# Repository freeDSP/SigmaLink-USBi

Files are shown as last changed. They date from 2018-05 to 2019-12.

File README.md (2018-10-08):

# SigmaLink USBi

The SigmaLink USBi is an all-in-one real-time programming interface.

MAIN COORDINATOR: [Max Chan](https://github.com/xcvista)

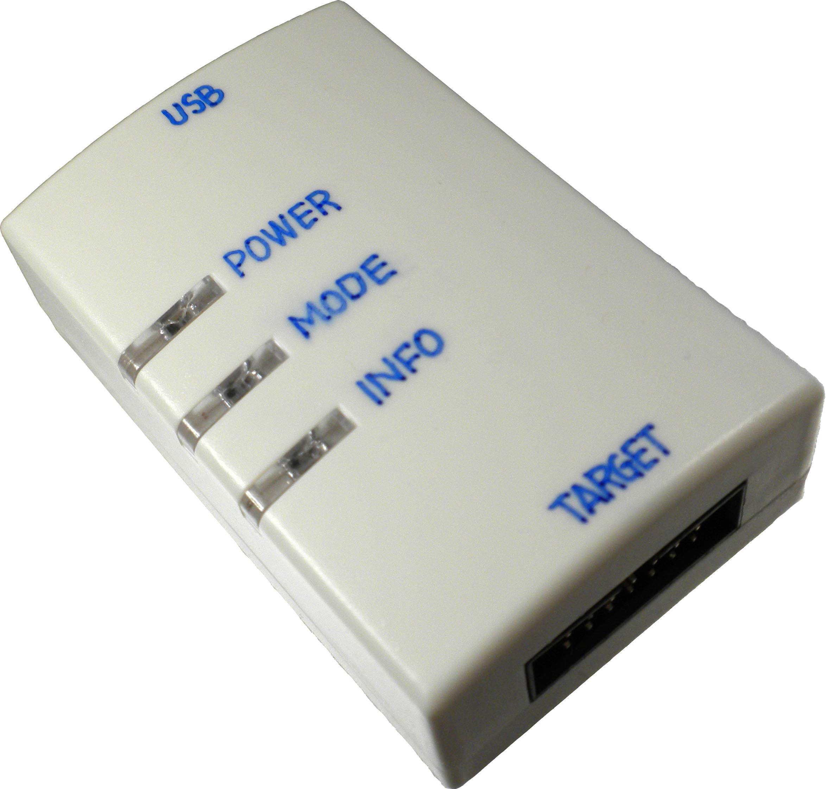
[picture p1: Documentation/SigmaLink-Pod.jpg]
SigmaLink USBi Pod Image


The SigmaLink USBi is a low-budget real-time programming device for the freeDSP and other DSP boards from Analog Devices. It is a new PCB design based on a CY7C68013 chip.

It has the same features as the Analog Devices USB interface (EVAL-ADUSB2EBZ), such as changing parameters while already using the freeDSP or easy changes of the schematic in SigmaStudio. You also can write your program to the EEPROM.

Please refer to the documentation for more information:

[Google Doc](https://docs.google.com/document/d/13BDac6Mss2I0CBOsSrk4YG-c8GQUpgU41vkwsMnYBss/edit?usp=sharing)

## License

This work and all other materials under https://github.com/freeDSP are licensed under a [Creative Commons Attribution Share-Alike 4.0 license](LICENSE.md). This allows for both personal and commercial derivative works, as long as they credit freeDSP and release their designs under the same license.

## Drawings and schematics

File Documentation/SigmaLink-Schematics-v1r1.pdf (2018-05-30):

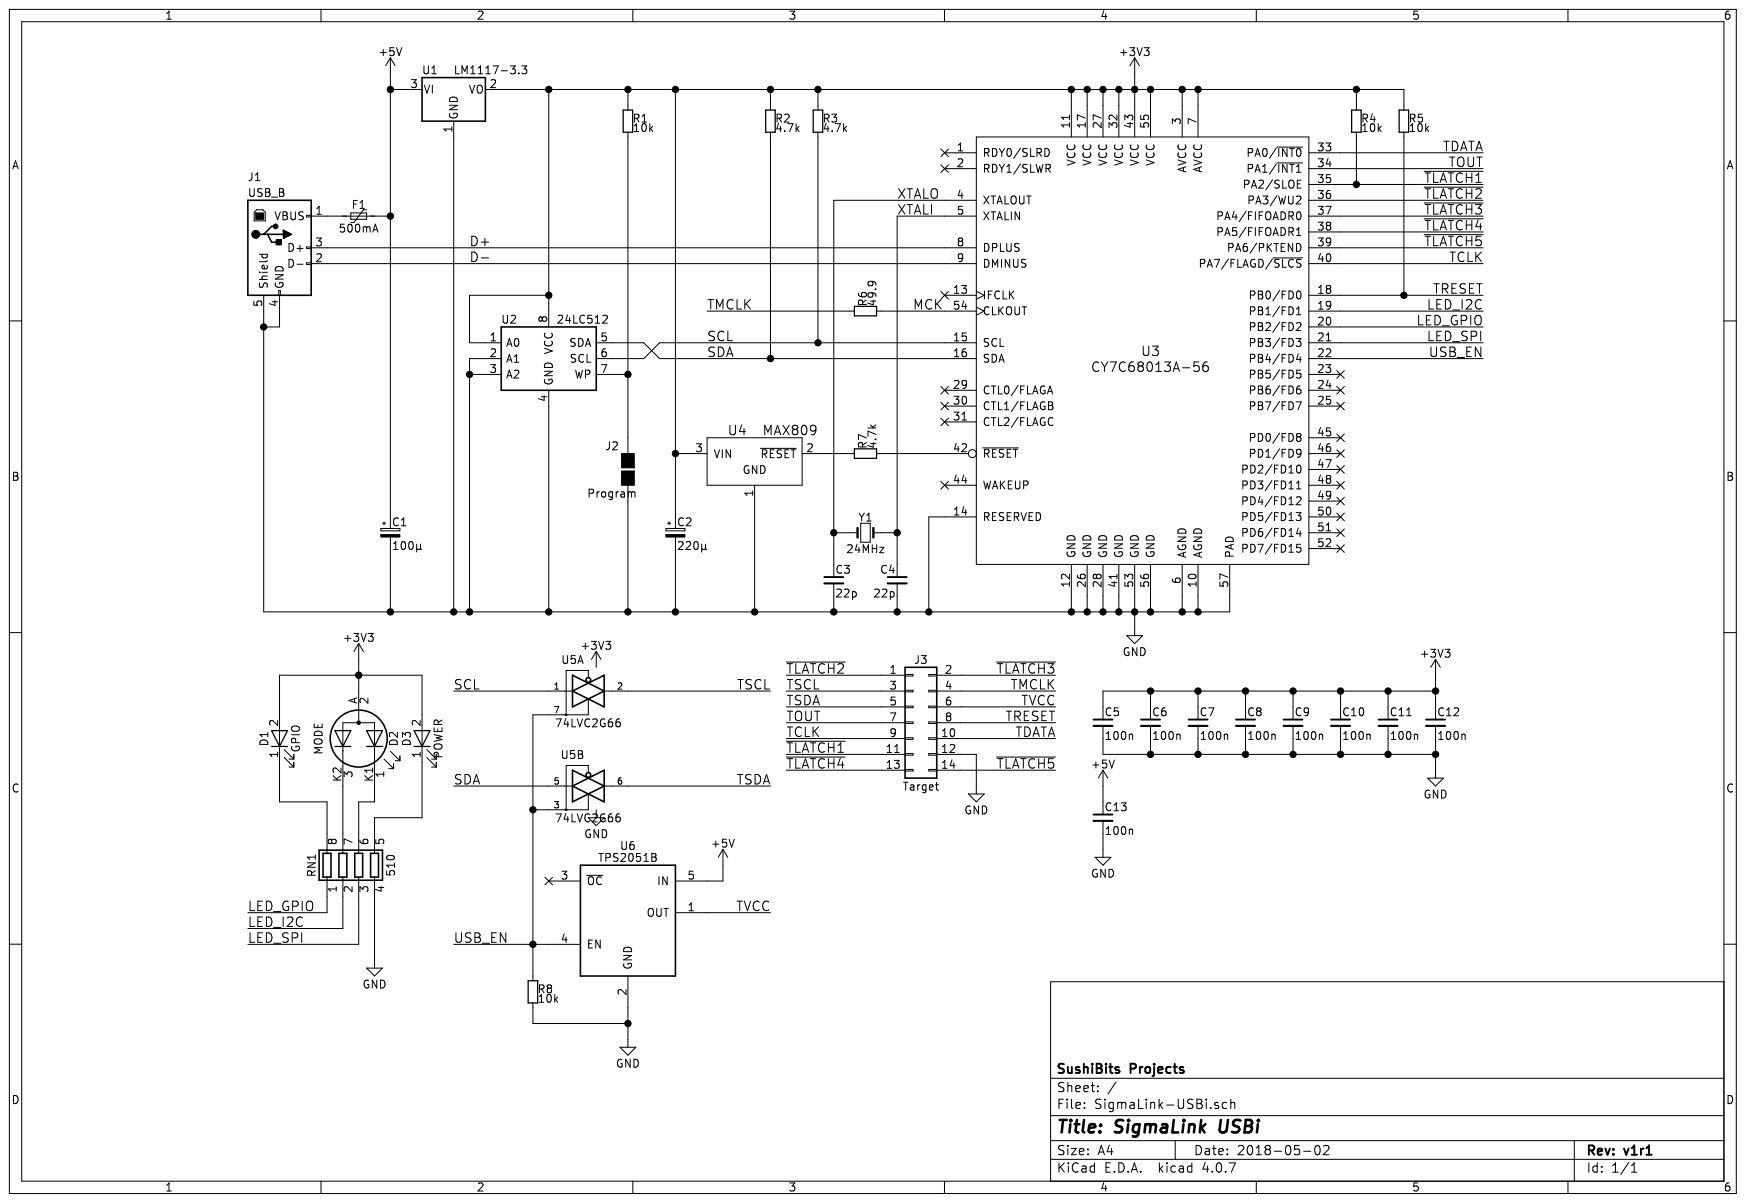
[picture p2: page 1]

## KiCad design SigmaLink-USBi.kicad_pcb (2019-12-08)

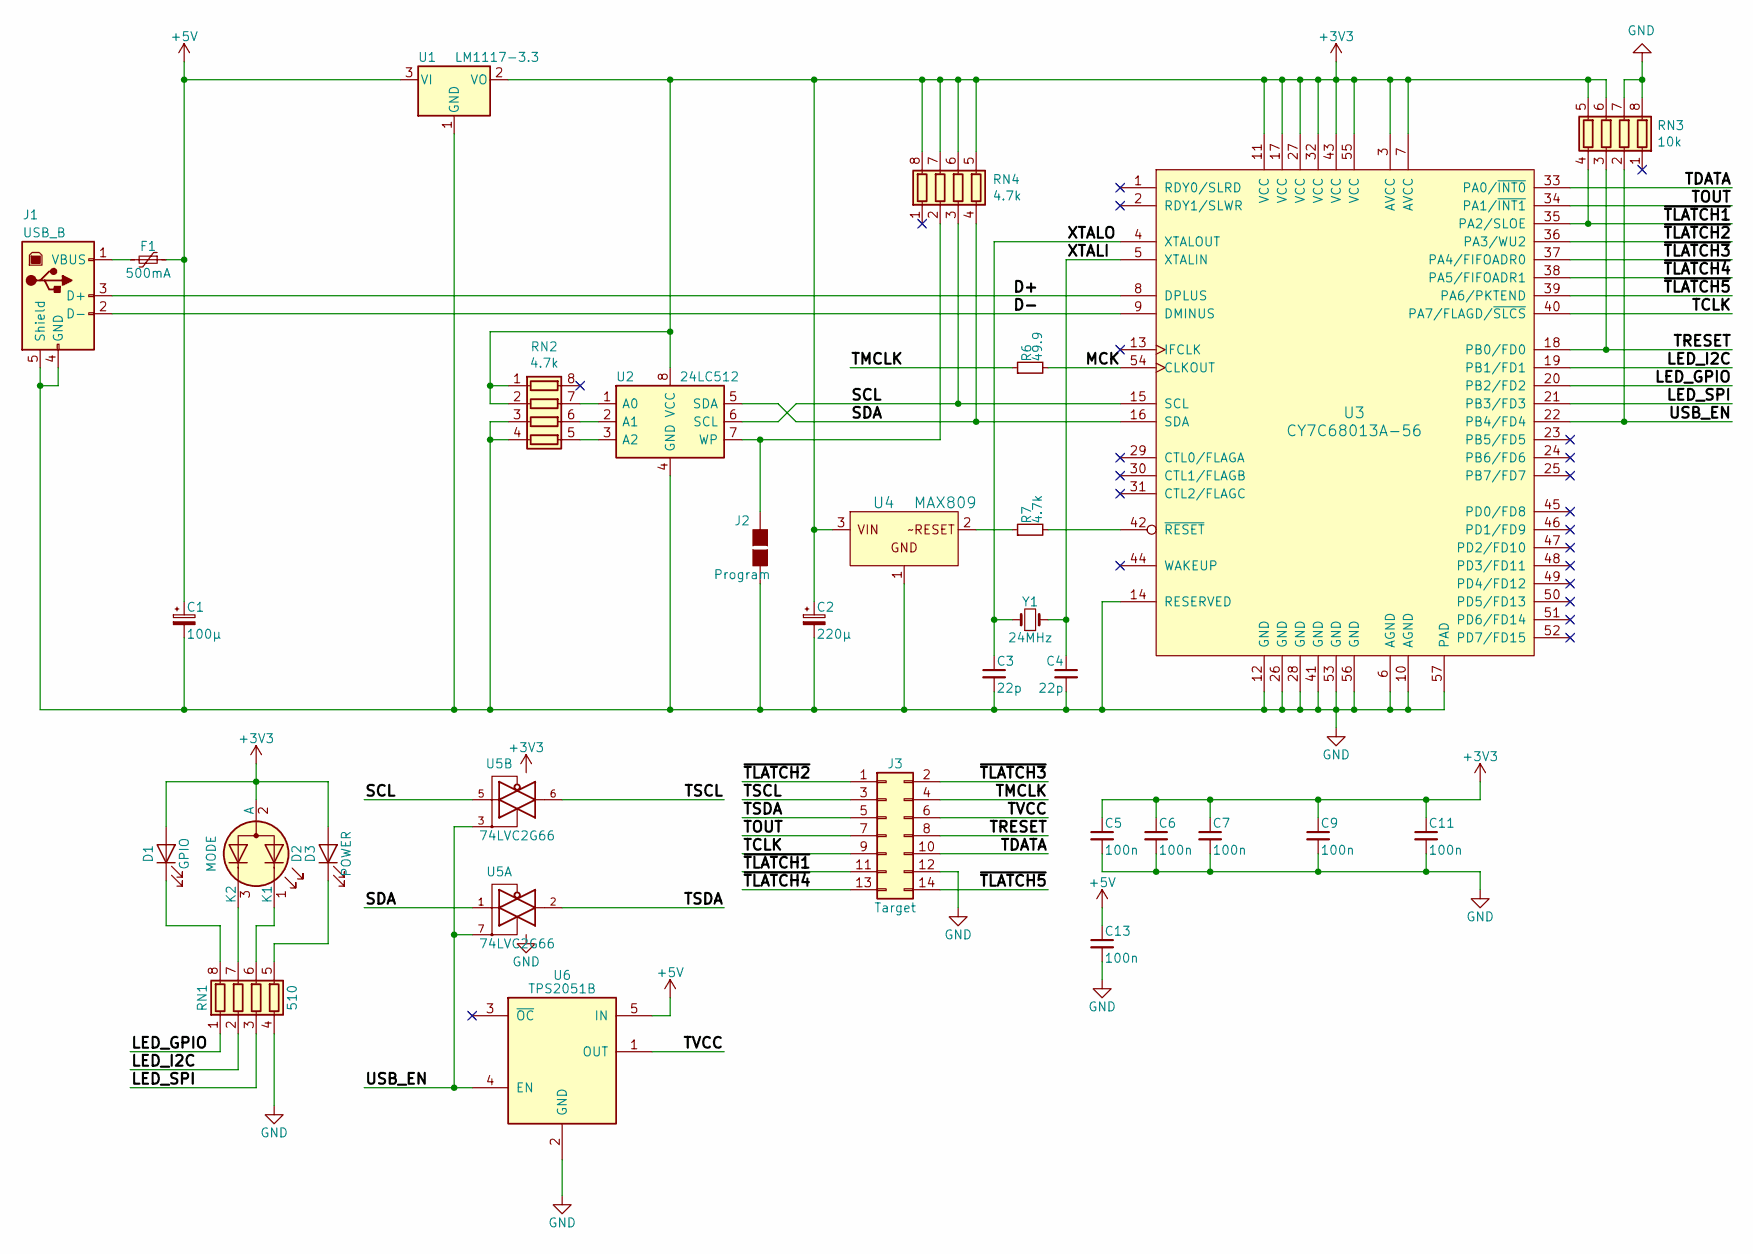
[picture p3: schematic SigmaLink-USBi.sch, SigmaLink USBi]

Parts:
C1: 100µ; CP_Elec_6.3x5.3
C2: 220µ; CP_Elec_6.3x5.3
C3, C4: 22p; C_0603_1608Metric_Pad1.05x0.95mm_HandSolder
C5, C6, C7, C9, C11, C13: 100n; C_0603_1608Metric_Pad1.05x0.95mm_HandSolder
D1: GPIO; LED_D3.0mm
D2: MODE; LED_D3.0mm-3
D3: POWER; LED_D3.0mm
F1: 500mA; Fuse_1812_4532Metric_Pad1.30x3.40mm_HandSolder
J1: USB_B; USB_B_OST_USB-B1HSxx_Horizontal
J2: Program; PinHeader_2x01_P1.27mm_Vertical
J3: Target; IDC-Header_2x07_P2.54mm_Horizontal
R6: 49.9; R_0603_1608Metric_Pad1.05x0.95mm_HandSolder
R7: 4.7k; R_0603_1608Metric_Pad1.05x0.95mm_HandSolder
RN1: 510; R_Array_Convex_4x0603
RN2, RN4: 4.7k; R_Array_Convex_4x0603
RN3: 10k; R_Array_Convex_4x0603
U1: LM1117-3.3; SOT-223-3_TabPin2
U2: 24LC512; SOIC-8_3.9x4.9mm_P1.27mm
U3: CY7C68013A-56; QFN-56-1EP_8x8mm_P0.5mm_EP4.6x5.3mm
U4: MAX809; SOT-23
U5: 74LVC2G66; VSSOP-8_3.0x3.0mm_P0.65mm
U6: TPS2051B; SOT-23-5
Y1: 24MHz; Crystal_SMD_5032-2Pin_5.0x3.2mm

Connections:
+5V: C1.1, C13.1, F1.1, U1.3 (VI), U6.5 (IN)
/D+: J1.3 (D+), U3.8 (DPLUS)
/D-: J1.2 (D-), U3.9 (DMINUS)
/LED_GPIO: RN1.1 (R1.1), U3.20 (PB2/FD2)
/LED_I2C: RN1.2 (R2.1), U3.19 (PB1/FD1)
/LED_SPI: RN1.3 (R3.1), U3.21 (PB3/FD3)
/MCK: R6.2, U3.54 (CLKOUT)
/SCL: RN4.3 (R3.1), U2.6 (SCL), U3.15 (SCL), U5.5
/SDA: RN4.4 (R4.1), U2.5 (SDA), U3.16 (SDA), U5.1
/TCLK: J3.9, U3.40 (PA7/FLAGD/~SLCS)
/TDATA: J3.10, U3.33 (PA0/~INT0)
/TMCLK: J3.4, R6.1
/TOUT: J3.7, U3.34 (PA1/~INT1)
/TRESET: J3.8, RN3.3 (R3.1), U3.18 (PB0/FD0)
/TSCL: J3.3, U5.6
/TSDA: J3.5, U5.2
/TVCC: J3.6, U6.1 (OUT)
/USB_EN: RN3.2 (R2.1), U3.22 (PB4/FD4), U5.3, U5.7, U6.4 (EN)
/XTALI: C4.1, U3.5 (XTALIN), Y1.2
/XTALO: C3.1, U3.4 (XTALOUT), Y1.1
/~TLATCH1: J3.11, RN3.4 (R4.1), U3.35 (PA2/SLOE)
/~TLATCH2: J3.1, U3.36 (PA3/WU2)
/~TLATCH3: J3.2, U3.37 (PA4/FIFOADR0)
/~TLATCH4: J3.13, U3.38 (PA5/FIFOADR1)
/~TLATCH5: J3.14, U3.39 (PA6/PKTEND)
GND: C1.2, C2.2, C3.2, C4.2, C5.2, C6.2, C7.2, C9.2, C11.2, C13.2, J1.4 (GND), J1.5 (Shield), J2.2 (G2), J3.12, RN1.4 (R4.1), RN2.3 (R3.1), RN2.4 (R4.1), RN3.7 (R2.2), RN3.8 (R1.2), U1.1 (GND), U2.4 (GND), U3.6 (AGND), U3.10 (AGND), U3.12 (GND), U3.14 (RESERVED), U3.26 (GND), U3.28 (GND), U3.41 (GND), U3.53 (GND), U3.56 (GND), U3.57 (PAD), U4.1 (GND), U5.4 (GND), U6.2 (GND)
unnamed: D1.1 (K), RN1.8 (R1.2)
unnamed: D2.1 (K1), RN1.6 (R3.2)
unnamed: D2.3 (K2), RN1.7 (R2.2)
unnamed: D3.1 (K), RN1.5 (R4.2)
unnamed: F1.2, J1.1 (VBUS)
unnamed: J2.1 (G1), RN4.2 (R2.1), U2.7 (WP)
unnamed: R7.1, U4.2 (~RESET)
unnamed: R7.2, U3.42 (~RESET)
unnamed: RN2.5 (R4.2), U2.3 (A2)
unnamed: RN2.6 (R3.2), U2.2 (A1)
unnamed: RN2.7 (R2.2), U2.1 (A0)

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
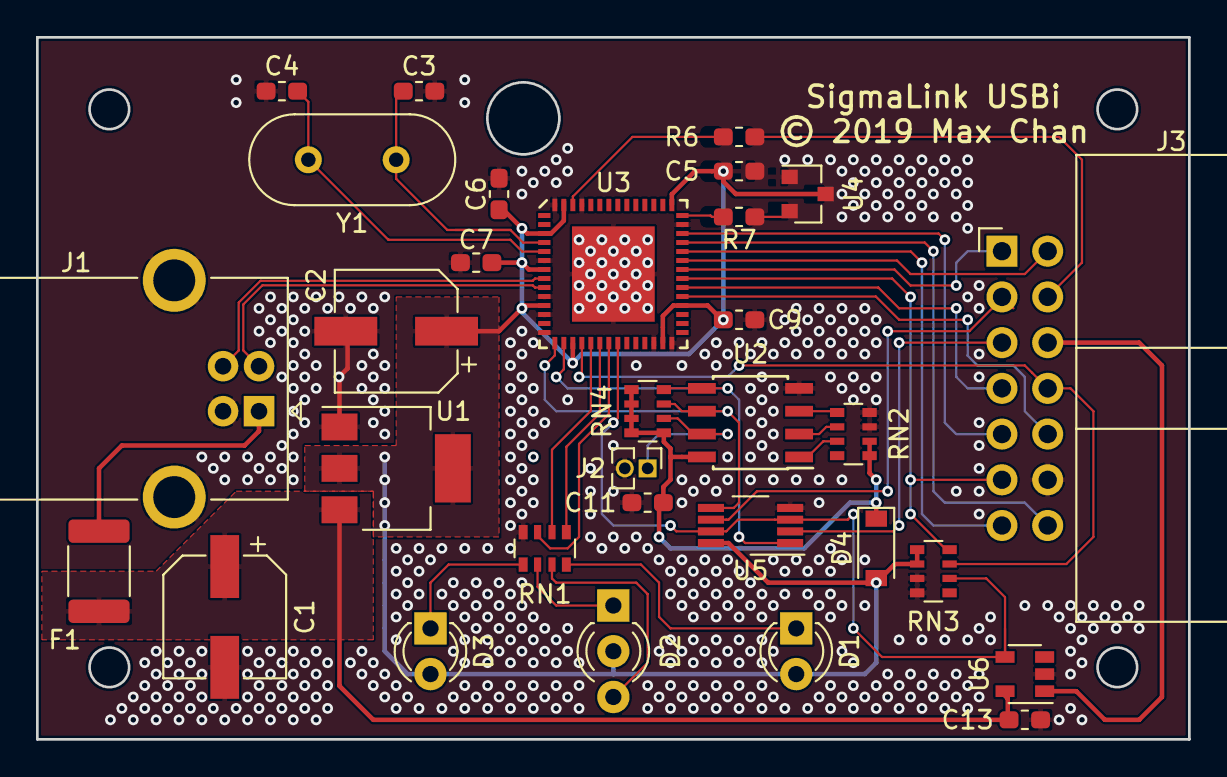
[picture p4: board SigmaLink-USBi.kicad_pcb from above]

Board: 2 copper layers, 64.0 x 39.0 mm, 31 parts (0 on the bottom side), 39 nets.

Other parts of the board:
D4: B5819W; D_SOD-123

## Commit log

2018-05-30 Bulk importing SigmaLink USBi source files
    [SigmaLink-USBi.kicad_pcb, SigmaLink-USBi.sch]
2018-05-30 I need pictures illustrating my point.
    [SigmaLink-USBi.kicad_pcb]
2018-05-30 Adding the schematics as Docs
2018-10-08 Preparing for v1r2
    [SigmaLink-USBi-2018-10-01-12-15-20.sch, SigmaLink-USBi.sch]
2018-10-08 Rerouted the board
    [SigmaLink-USBi.kicad_pcb, SigmaLink-USBi.sch]
2018-10-08 Peparing release: v2r1
    [SigmaLink-USBi.kicad_pcb, SigmaLink-USBi.sch]
2018-10-08 Touchup: NoConn's
    [SigmaLink-USBi.sch]
2019-04-26 Resistor packs are used more extensively.
    Also a re-layout.
    [SigmaLink-USBi.kicad_pcb, SigmaLink-USBi.sch]
2019-04-26 Update SigmaLink-USBi.sch
    Update version number.
    [SigmaLink-USBi.sch]
2019-04-26 Timestamp change?
    [SigmaLink-USBi.kicad_pcb]
2019-12-08 General maintanence commit.
    [SigmaLink-USBi.kicad_pcb]

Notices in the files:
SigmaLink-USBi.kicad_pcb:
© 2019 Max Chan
